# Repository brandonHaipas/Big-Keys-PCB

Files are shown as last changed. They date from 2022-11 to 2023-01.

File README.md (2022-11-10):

# Big-Keys-PCB

In this repository I will be updating the files needed to print the PCB for the InCA:Big-Keys keyboard, which aim is to augmentate communication between human and non-human animals, specifically medium size non-human animals.
I'll be updating more details in [the project's page](https://bigkeys.incalab.cl/).
For the development of this project I followed the mechanical PCB guide made by ai03, [here's the guide](https://wiki.ai03.com/books/pcb-design/chapter/pcb-designer-guide) if you want to create your own keypad or keyboard.

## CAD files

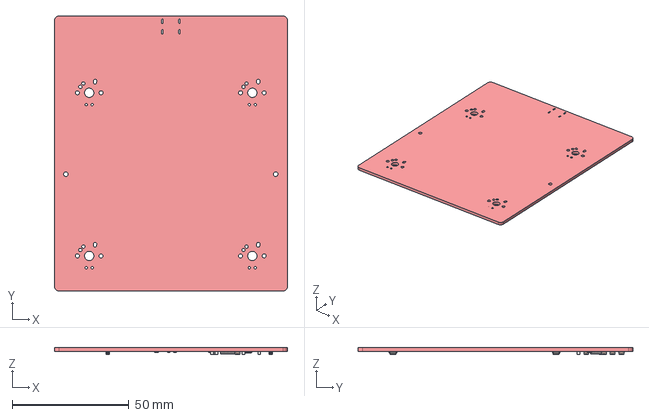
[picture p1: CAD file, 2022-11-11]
BigKeysPCB.step
100.0 x 118.0 x 2.90 mm
BigKeysPCB PCB

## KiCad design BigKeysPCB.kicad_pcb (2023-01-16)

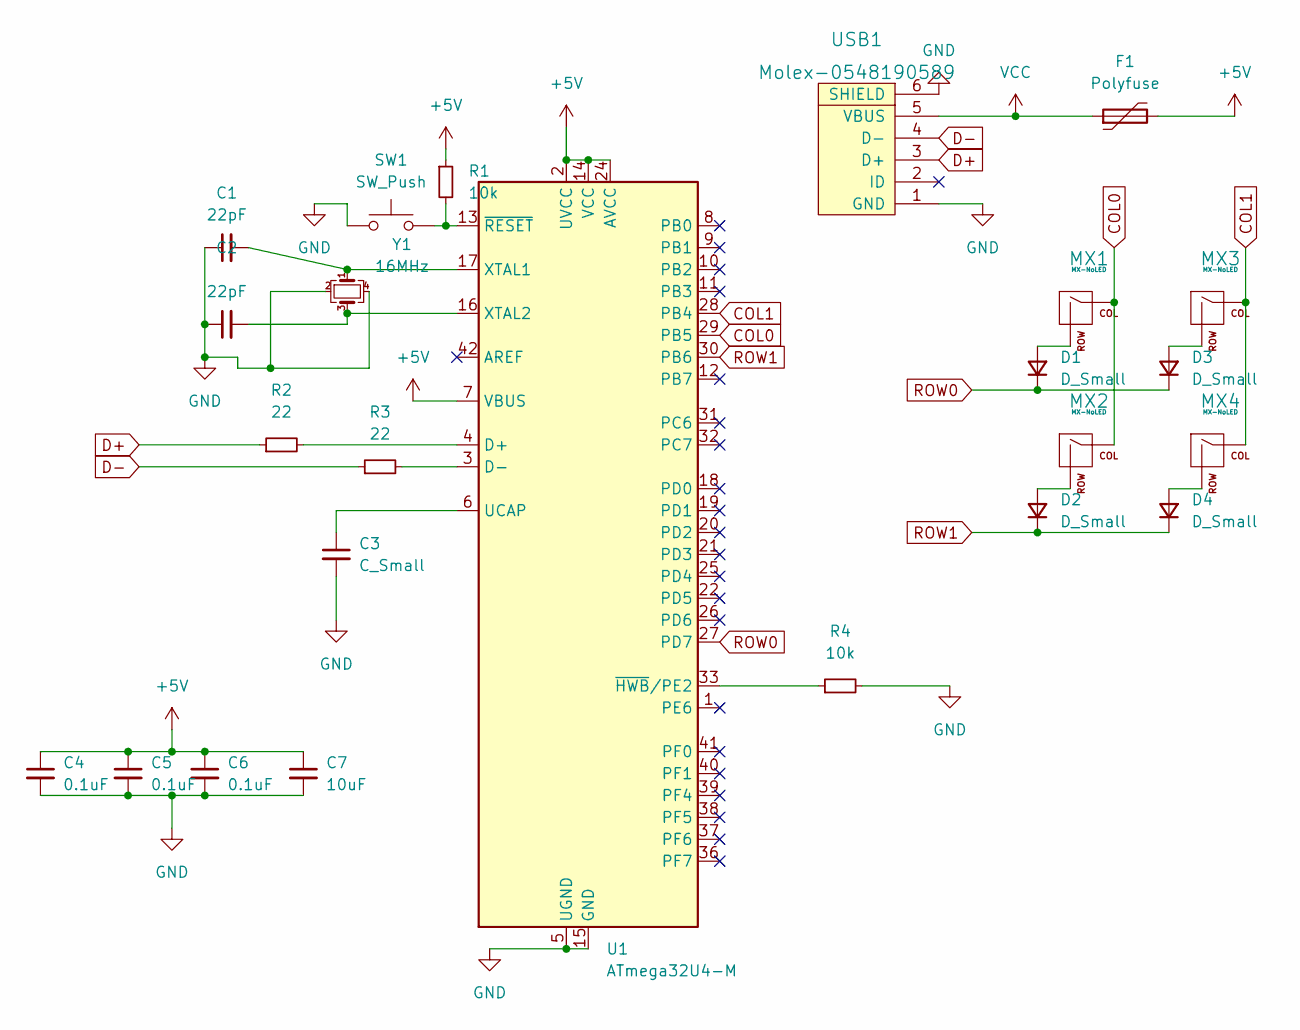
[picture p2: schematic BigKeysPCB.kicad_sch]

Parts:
C1, C2: 22pF; C_0805_2012Metric
C3: C_Small; C_0805_2012Metric
C4, C5, C6: 0.1uF; C_0805_2012Metric
C7: 10uF; C_0805_2012Metric
D1, D2, D3, D4: D_Small; D_SOD-123
F1: Polyfuse; Fuse_1206_3216Metric
MX1, MX2, MX3, MX4: MX-NoLED; MX-1U
R1, R4: 10k; R_0805_2012Metric
R2, R3: 22; R_0805_2012Metric
SW1: SW_Push; SKQG-1155865
U1: ATmega32U4-M; QFN-44-1EP_7x7mm_P0.5mm_EP5.2x5.2mm
USB1: Molex-0548190589
Y1: 16MHz; Crystal_SMD_3225-4Pin_3.2x2.5mm

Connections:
+5V: C4.1, C5.1, C6.1, C7.1, F1.2, R1.1, U1.2 (UVCC), U1.7 (VBUS), U1.14 (VCC), U1.24 (AVCC), U1.34 (VCC), U1.44 (AVCC)
COL0: MX1.1 (COL), MX2.1 (COL), U1.29 (PB5)
COL1: MX3.1 (COL), MX4.1 (COL), U1.28 (PB4)
D+: R2.1, USB1.3 (D+)
D-: R3.1, USB1.4 (D-)
GND: C1.1, C2.1, C3.2, C4.2, C5.2, C6.2, C7.2, R4.2, SW1.1, U1.5 (UGND), U1.15 (GND), U1.23 (GND), U1.35 (GND), U1.43 (GND), U1.45 (GND), USB1.1 (GND), USB1.6 (SHIELD), Y1.2, Y1.4
unnamed: C1.2, U1.17 (XTAL1), Y1.1
unnamed: C2.2, U1.16 (XTAL2), Y1.3
unnamed: C3.1, U1.6 (UCAP)
unnamed: D1.2 (A), MX1.2 (ROW)
unnamed: D2.2 (A), MX2.2 (ROW)
unnamed: D3.2 (A), MX3.2 (ROW)
unnamed: D4.2 (A), MX4.2 (ROW)
unnamed: R1.2, SW1.2, U1.13 (~RESET)
unnamed: R2.2, U1.4 (D+)
unnamed: R3.2, U1.3 (D-)
unnamed: R4.1, U1.33 (~HWB/PE2)
ROW0: D1.1 (K), D3.1 (K), U1.27 (PD7)
ROW1: D2.1 (K), D4.1 (K), U1.30 (PB6)
VCC: F1.1, USB1.5 (VBUS)

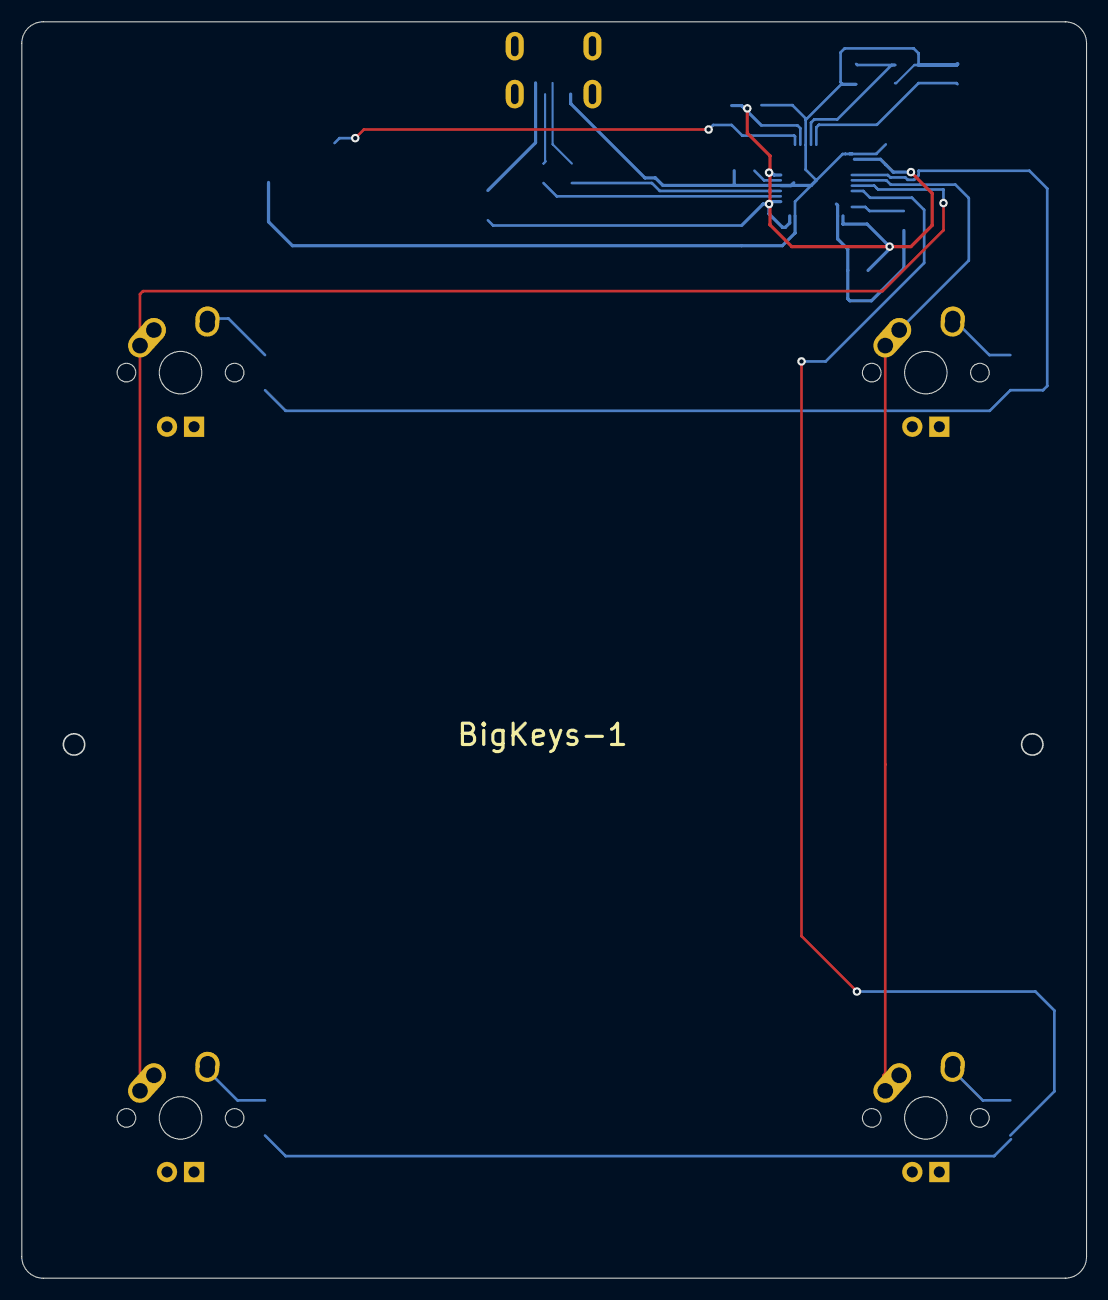
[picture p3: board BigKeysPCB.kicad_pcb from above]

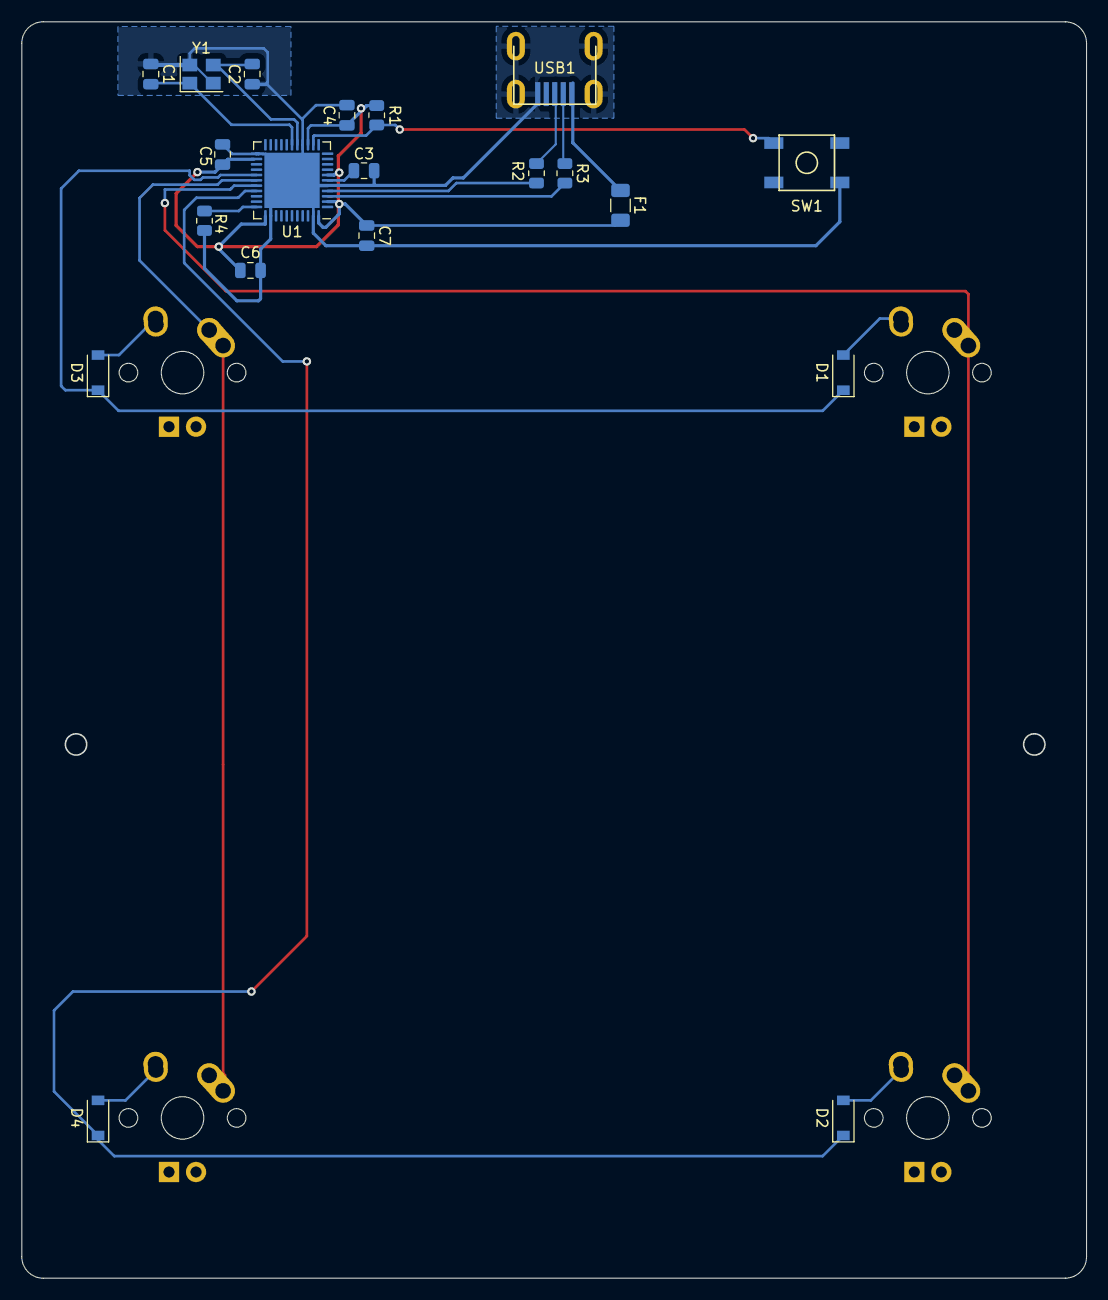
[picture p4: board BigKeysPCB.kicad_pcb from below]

Board: 2 copper layers, 100.0 x 118.0 mm, 24 parts (20 on the bottom side), 20 nets.

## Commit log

2022-10-18 libraries added as local in both schematics and PCB files
2022-10-18 MCU schematics done
    [BigKeysPCB.kicad_sch]
2022-10-18 schematics and footprint bindings ready for importing to PCB layout
    [BigKeysPCB.kicad_sch]
2022-10-18 preliminary PCB design
2022-11-09 first prototype finished
    [BigKeysPCB.kicad_pcb, BigKeysPCB.step]
2022-11-10 changed the soldering mask color from green to red
    [BigKeysPCB.kicad_pcb]
2022-11-10 changed plate moount holes dimensions to fit M2 screws
    [BigKeysPCB.kicad_pcb]
2022-11-10 changed wiring, some errors and warnings solved
    [BigKeysPCB.kicad_pcb]
2022-11-11 correct measures for 3D case and plate model
    [BigKeysPCB.kicad_pcb, BigKeysPCB.step]
2022-11-14 shield connected to ground, missing connection added to pcb file
    [BigKeysPCB.kicad_pcb, BigKeysPCB.kicad_sch]
2022-11-16 mx-only library added to the PCB file
2023-01-16 most of ERC and ERC errors debugged
    [BigKeysPCB-B_Cu.gbr, BigKeysPCB-B_Mask.gbr, BigKeysPCB-B_Paste.gbr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]
2023-01-16 final version of first prototype
    [BigKeysPCB.kicad_pcb]
